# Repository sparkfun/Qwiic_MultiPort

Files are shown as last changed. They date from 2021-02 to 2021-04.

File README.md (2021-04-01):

Qwiic MultiPort
========================================

SparkFun Qwiic MultiPort (https://www.sparkfun.com/products/18012)

[*SparkFun Qwiic MultiPort (BOB-18012)*](https://www.sparkfun.com/products/18012)

Qwiic is a very efficient way to quickly prototype an idea but not all Qwiic-enabled devices have two ports. The SparkFun Qwiic MultiPort adds additional ports to boards that have only one Qwiic port on the I2C bus. Once added, you can use it as a hub to add as many I2C devices to the bus as you need! Included are mounting holes so that the board can be secured to any system.

Repository Contents
-------------------

* **/Hardware** - Eagle design files (.brd, .sch)
* **/Production** - Production panel files (.brd)

Documentation
--------------
* **[Hookup Guide](https://learn.sparkfun.com/tutorials/1659)**

Product Versions
----------------
* [BOB-18012](https://www.sparkfun.com/products/18012) - Initial Release

License Information
-------------------

This product is _**open source**_! 

Please review the LICENSE.md file for license information. 

If you have any questions or concerns on licensing, please contact technical support on our [SparkFun forums](https://forum.sparkfun.com/viewforum.php?f=152).

Distributed as-is; no warranty is given.

- Your friends at SparkFun.

_<COLLABORATION CREDIT>_

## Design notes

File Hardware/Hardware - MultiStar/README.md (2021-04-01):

Qwiic MultiStar
========================================

SparkFun Qwiic MultiStar (https://www.sparkfun.com/news/3803)

[*SparkFun Qwiic MultiStar (BOB-?????)*](https://www.sparkfun.com/news/3803)

The MultiStar was designed for April Fools' Day! This board functions like the MultiPort but with an additional Qwiic connector. The board is also shaped like a Ninja star! The following folders include the Eagle files for the MultiStar. For more information, check out the blog post under "[A Sneak Preview of Our Latest Qwiic Product](https://www.sparkfun.com/news/3803)."

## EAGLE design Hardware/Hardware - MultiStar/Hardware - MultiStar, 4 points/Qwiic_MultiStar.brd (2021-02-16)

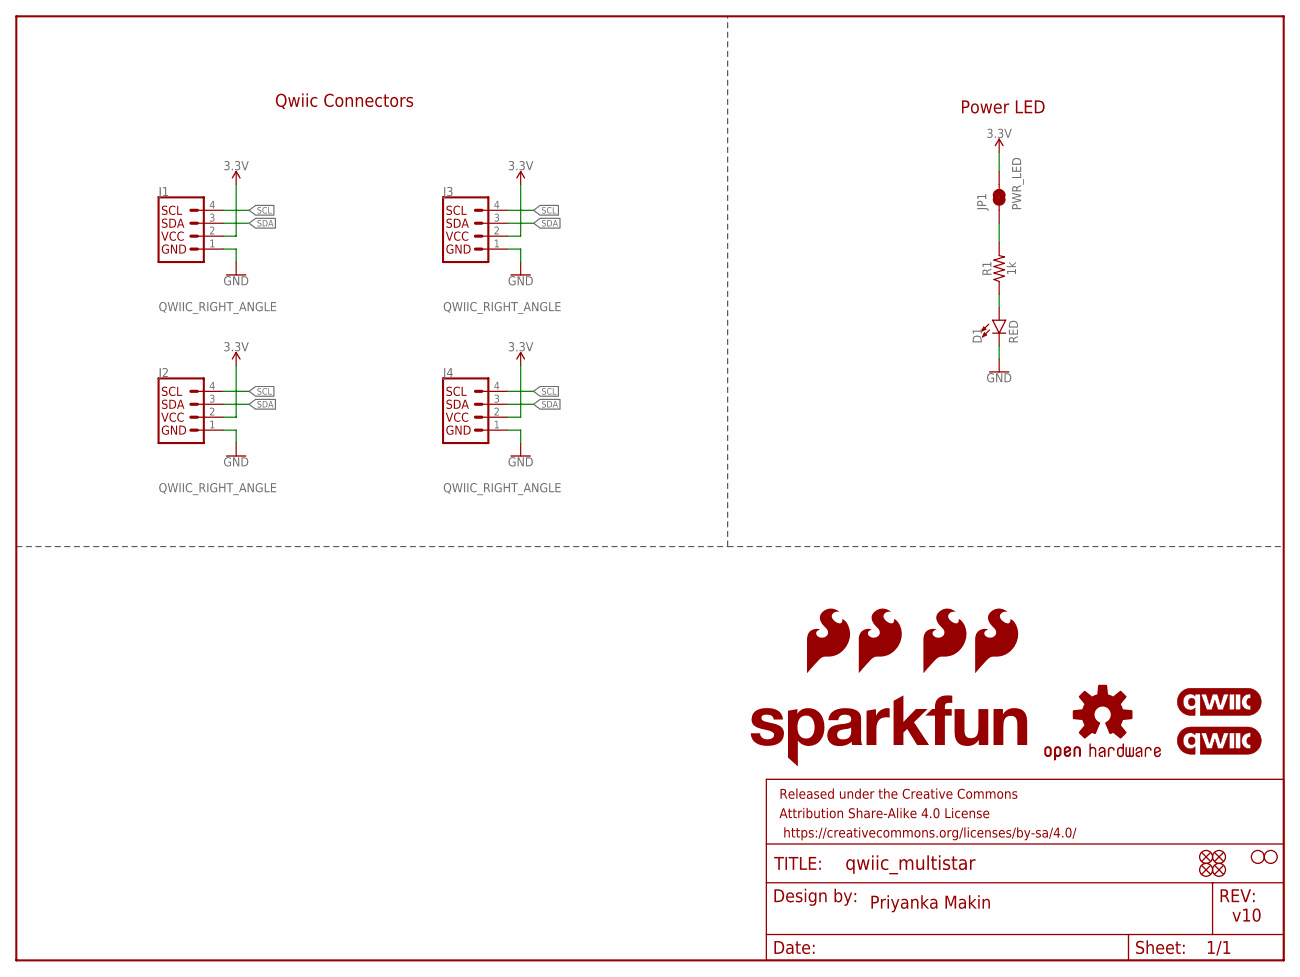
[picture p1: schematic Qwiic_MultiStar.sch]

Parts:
D1: RED; LED-0603
FD1, FD2, FD3, FD4: FIDUCIAL1X2; FIDUCIAL-1X2
FRAME1: FRAME-LETTER; CREATIVE_COMMONS
H1, H2: STAND-OFFTIGHT; STAND-OFF-TIGHT
J1, J2, J3, J4: QWIIC_RIGHT_ANGLE; JST04_1MM_RA
JP1: PWR_LED; SMT-JUMPER_2_NC_TRACE_SILK
LOGO1, LOGO2: QWIIC_LOGO_5MM; QWIIC_5MM
LOGO3: OSHW-LOGOS; OSHW-LOGO-S
LOGO4: SFE_LOGO_NAME.2_INCH; SFE_LOGO_NAME_.2
LOGO5, LOGO6, LOGO7, LOGO8: SFE_LOGO_FLAME.1_INCH; SFE_LOGO_FLAME_.1
R1: 1k; 0603

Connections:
3.3V: J1.2, J2.2, J3.2, J4.2, JP1.2
GND: D1.C, J1.1, J2.1, J3.1, J4.1
unnamed: D1.A, R1.1
unnamed: JP1.1, R1.2
SCL: J1.4, J2.4, J3.4, J4.4
SDA: J1.3, J2.3, J3.3, J4.3

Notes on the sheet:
Priyanka Makin
v10
Qwiic Connectors
Power LED

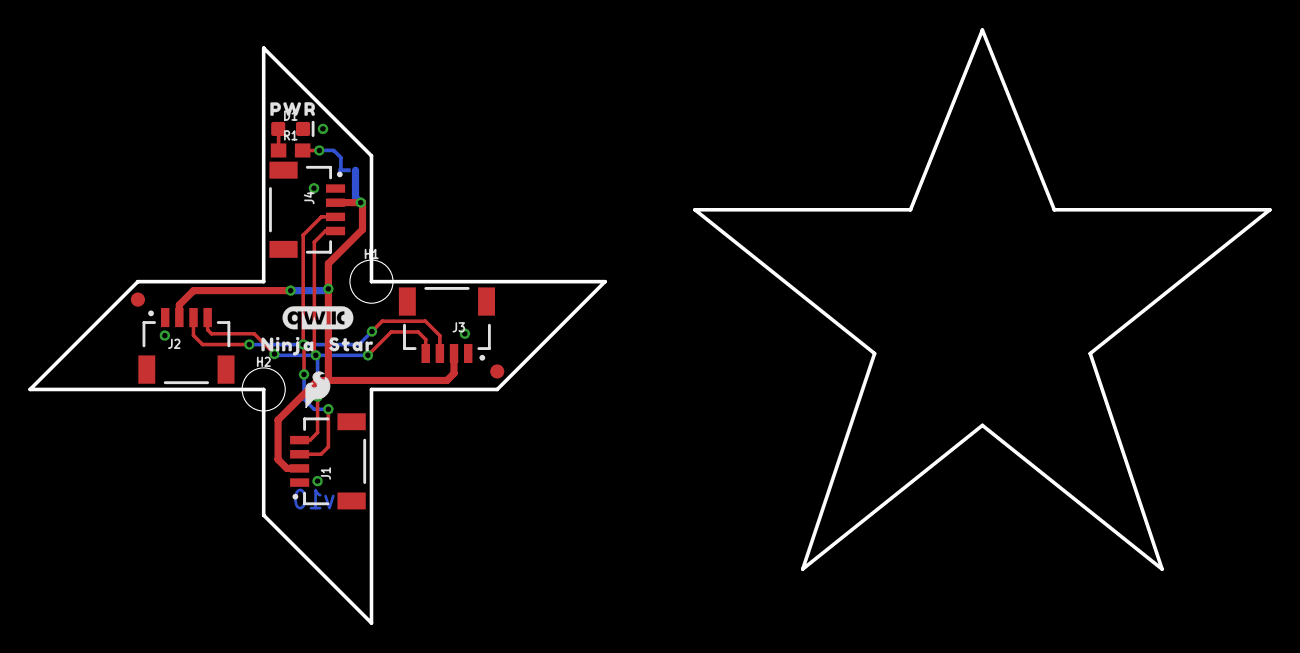
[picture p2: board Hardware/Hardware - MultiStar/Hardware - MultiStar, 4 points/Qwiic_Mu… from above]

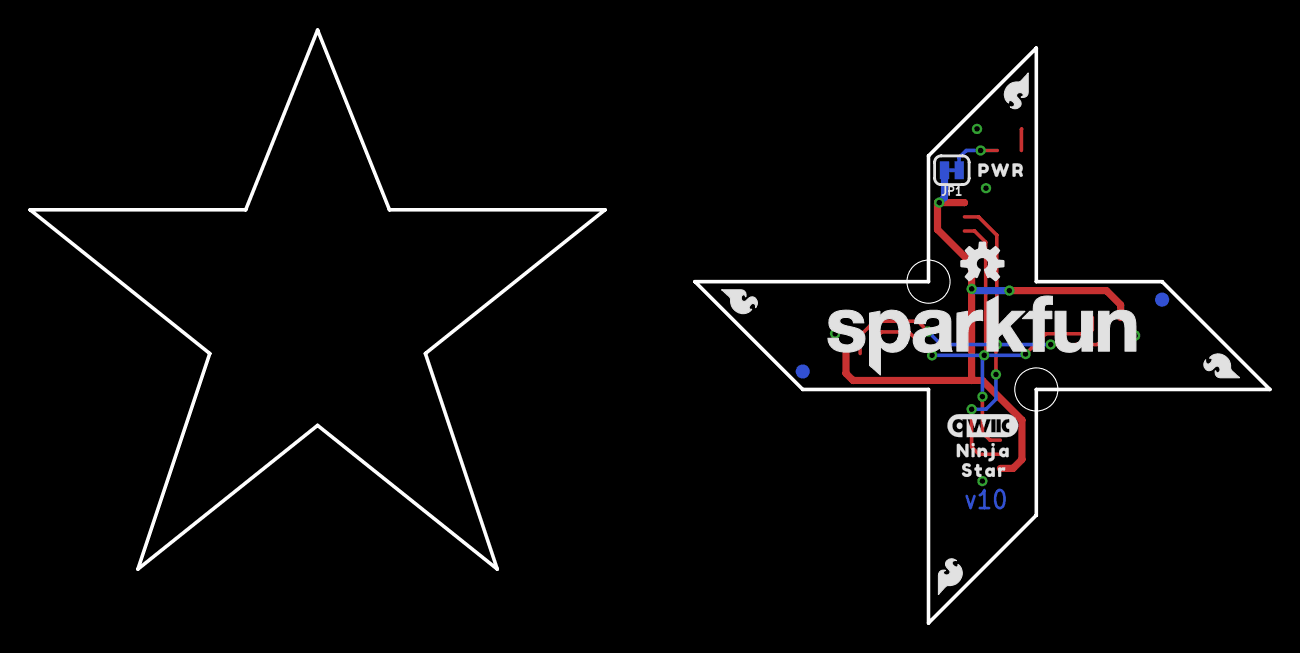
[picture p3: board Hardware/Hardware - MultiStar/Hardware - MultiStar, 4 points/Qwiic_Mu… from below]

Board: 2 copper layers, 40.6 x 40.6 mm, 29 parts (13 on the bottom side), 6 nets.

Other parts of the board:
U$2: SFE_LOGO_FLAME_.1
U$3, U$5: NINJA0
U$4, U$9: PWR0
U$6, U$7: STAR0

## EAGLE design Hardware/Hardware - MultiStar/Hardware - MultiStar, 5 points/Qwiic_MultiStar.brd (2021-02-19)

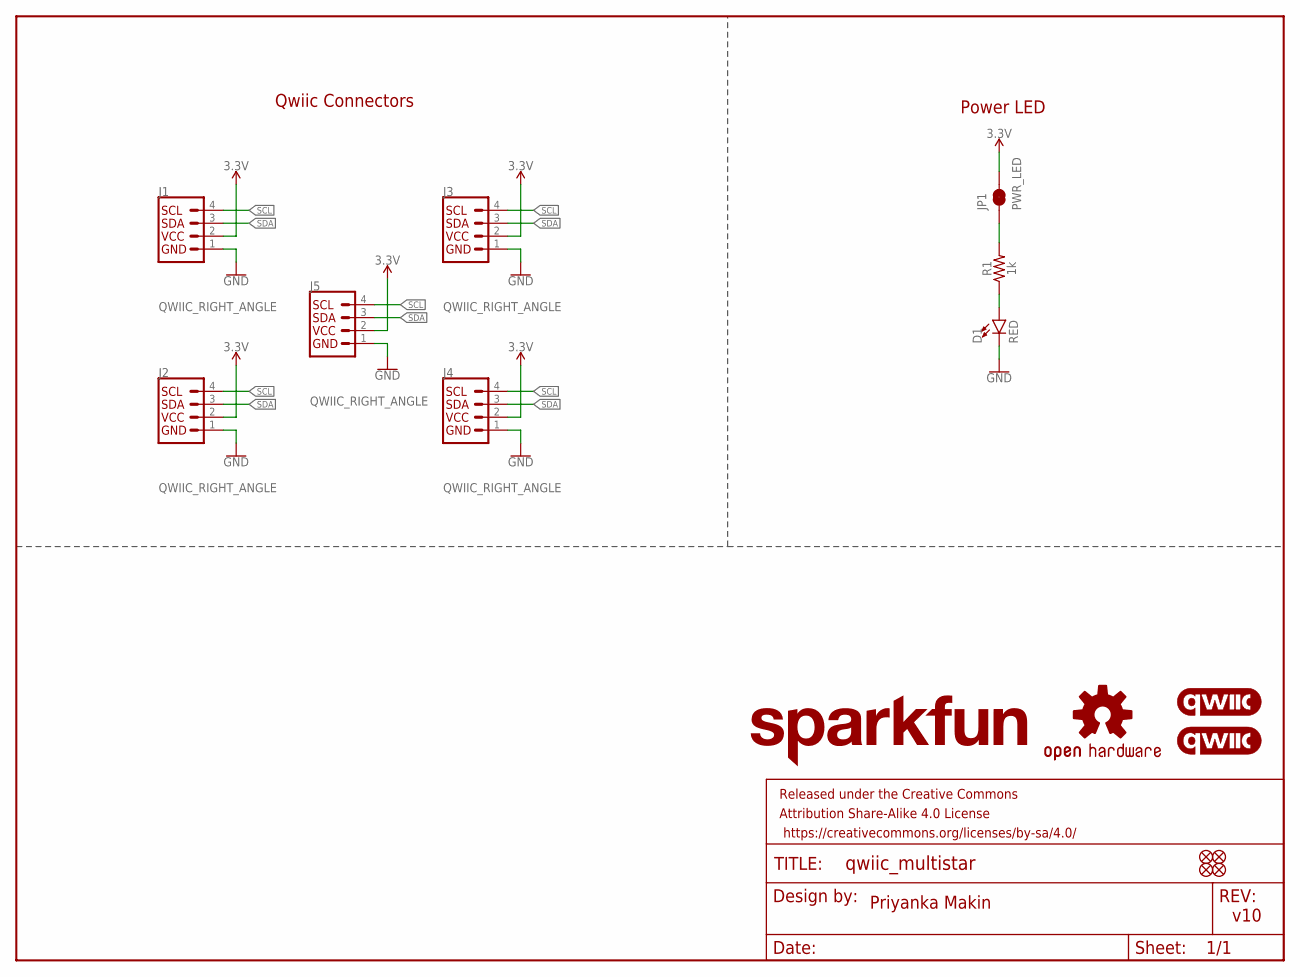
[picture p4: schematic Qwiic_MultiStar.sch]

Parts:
D1: RED; LED-0603
FD1, FD2, FD3, FD4: FIDUCIAL1X2; FIDUCIAL-1X2
FRAME1: FRAME-LETTER; CREATIVE_COMMONS
J1, J2, J3, J4, J5: QWIIC_RIGHT_ANGLE; JST04_1MM_RA
JP1: PWR_LED; SMT-JUMPER_2_NC_TRACE_SILK
LOGO1, LOGO2: QWIIC_LOGO_5MM; QWIIC_5MM
LOGO3: OSHW-LOGOS; OSHW-LOGO-S
LOGO4: SFE_LOGO_NAME.2_INCH; SFE_LOGO_NAME_.2
R1: 1k; 0603

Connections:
3.3V: J1.2, J2.2, J3.2, J4.2, J5.2, JP1.2
GND: D1.C, J1.1, J2.1, J3.1, J4.1, J5.1
unnamed: D1.A, R1.1
unnamed: JP1.1, R1.2
SCL: J1.4, J2.4, J3.4, J4.4, J5.4
SDA: J1.3, J2.3, J3.3, J4.3, J5.3

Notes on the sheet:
Priyanka Makin
v10
Qwiic Connectors
Power LED

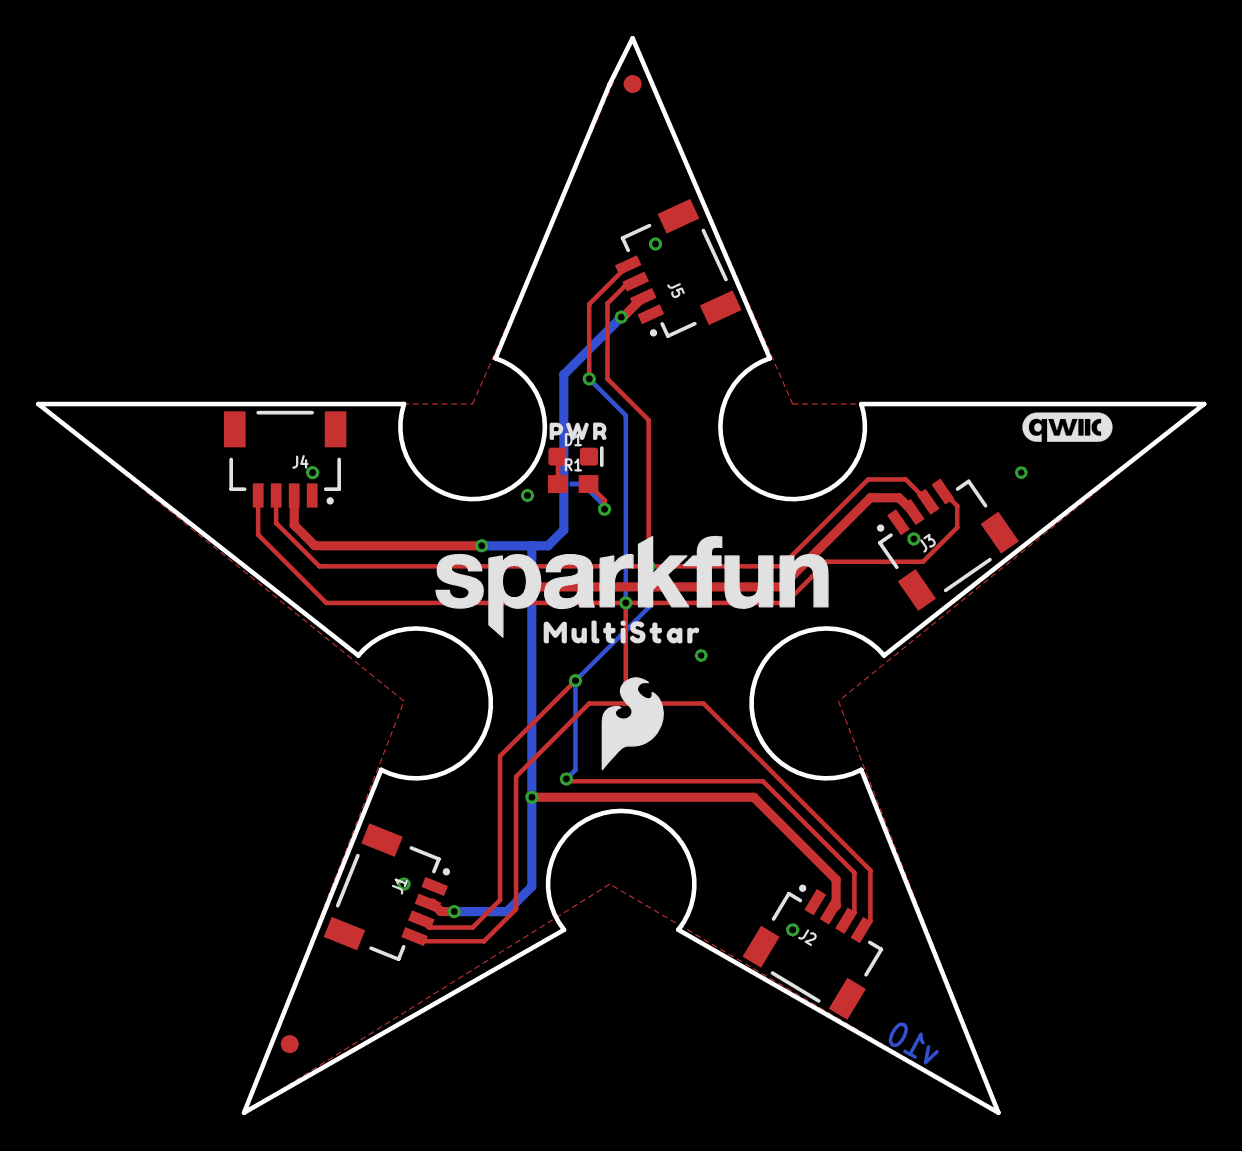
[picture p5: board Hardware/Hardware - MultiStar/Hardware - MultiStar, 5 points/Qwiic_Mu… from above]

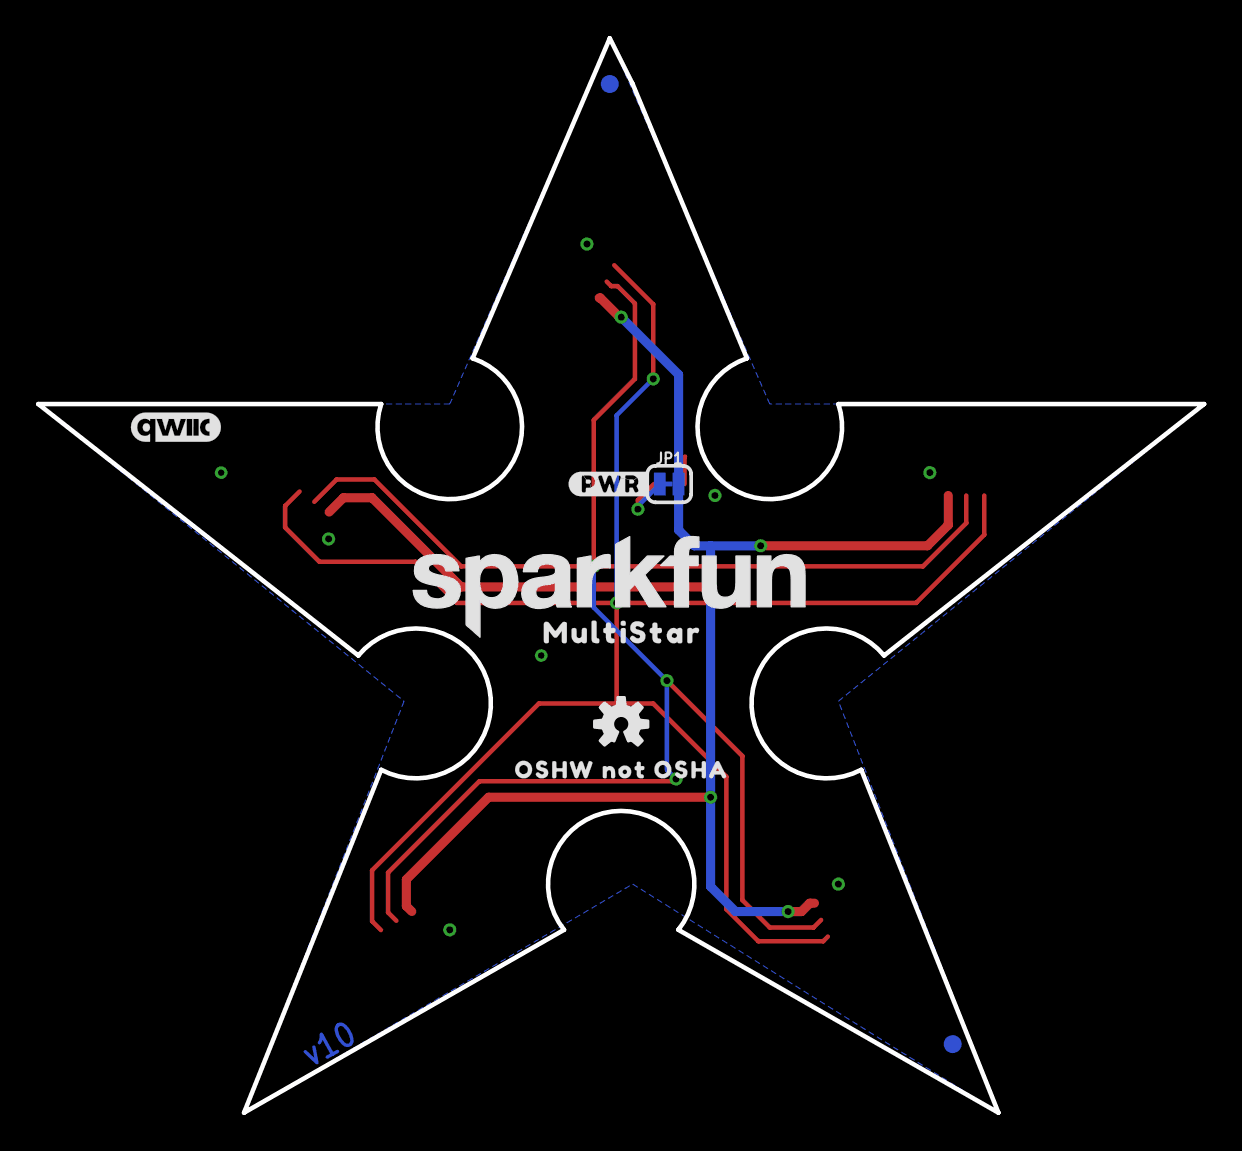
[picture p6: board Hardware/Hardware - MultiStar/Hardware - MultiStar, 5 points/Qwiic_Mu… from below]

Board: 2 copper layers, 64.8 x 59.7 mm, 24 parts (9 on the bottom side), 6 nets.

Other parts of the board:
LOGO5: SFE_LOGO_NAME.2_INCH; SFE_LOGO_NAME_.2
U$1: OSHW_NOT_OSHA0
U$2: SFE_LOGO_FLAME_.2
U$3, U$5: MULTISTAR0
U$6: #PWR#0
U$9: PWR0

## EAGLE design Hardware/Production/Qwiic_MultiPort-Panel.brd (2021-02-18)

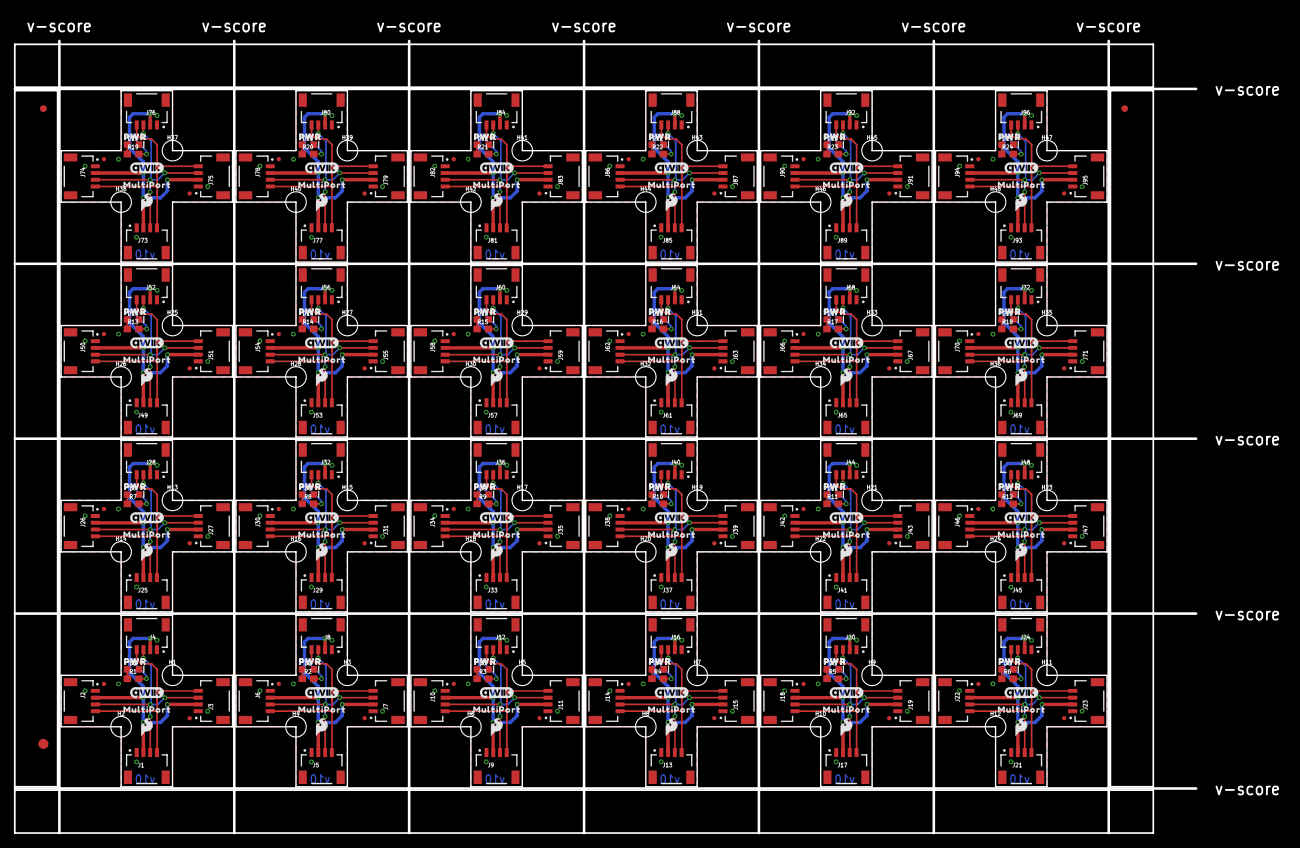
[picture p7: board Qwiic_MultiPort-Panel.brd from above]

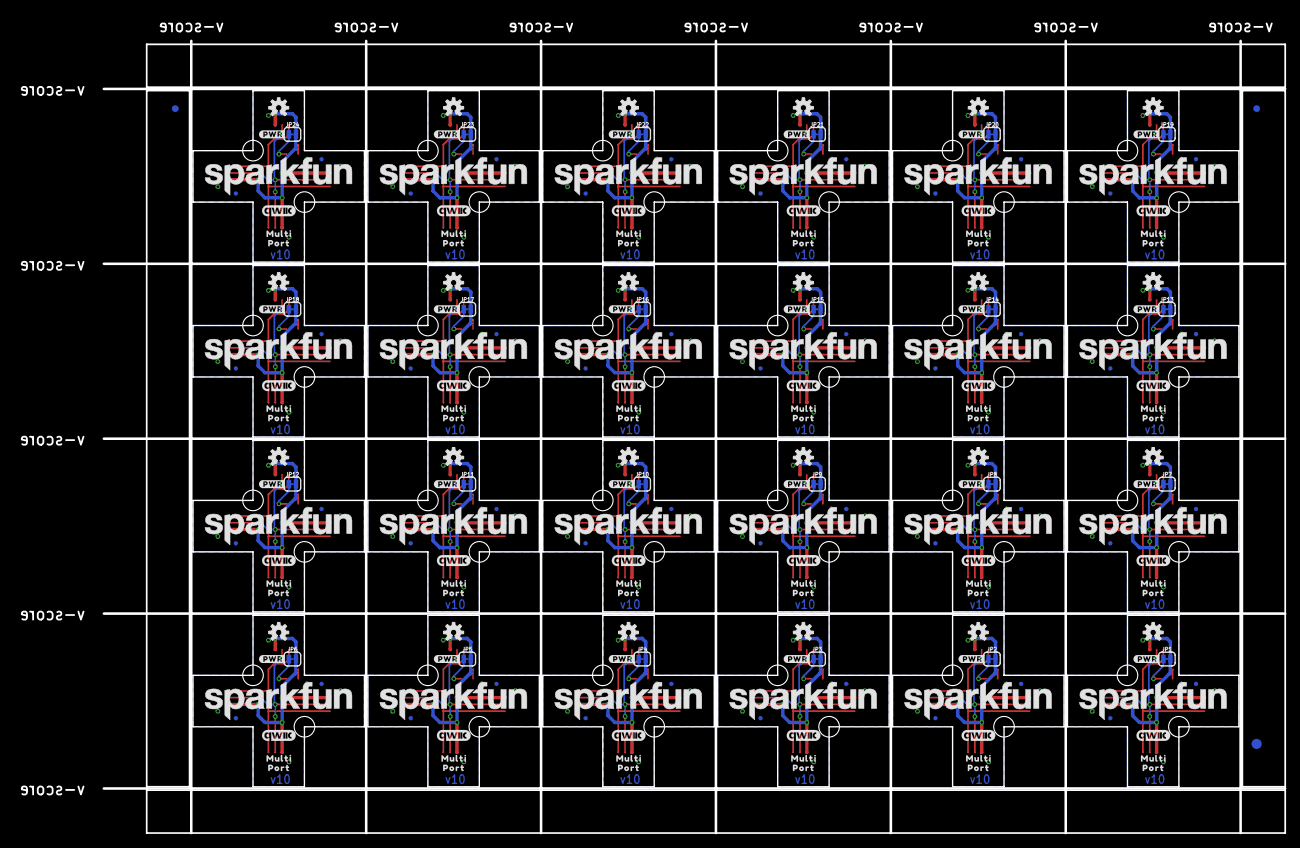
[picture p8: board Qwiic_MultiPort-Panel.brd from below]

Board: 2 copper layers, 175.0 x 117.3 mm, 582 parts (219 on the bottom side), 144 nets.

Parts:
D1, D2, D3, D4, D5, D6, D7, D8, D9, D10, D11, D12, D13, D14, D15, D16, D17, D18, D19, D20, D21, D22, D23, D24: RED; LED-0603
E$1, E$2, E$3, E$4: FIDUCIAL-1X2
E$5, E$6: FIDUCIAL-1.5X3
FD1, FD2, FD3, FD4, FD5, FD6, FD7, FD8, FD9, FD10, FD11, FD12, FD13, FD14, FD15, FD16, FD17, FD18, FD19, FD20, FD21, FD22, FD23, FD24, FD25, FD26, FD27, FD28, FD29, FD30, FD31, FD32, FD33, FD34, FD35, FD36, FD37, FD38, FD39, FD40, FD41, FD42, FD43, FD44, FD45, FD46, FD47, FD48, FD49, FD50, FD51, FD52, FD53, FD54, FD55, FD56, FD57, FD58, FD59, FD60, FD61, FD62, FD63, FD64, FD65, FD66, FD67, FD68, FD69, FD70, FD71, FD72, FD73, FD74, FD75, FD76, FD77, FD78, FD79, FD80, FD81, FD82, FD83, FD84, FD85, FD86, FD87, FD88, FD89, FD90, FD91, FD92, FD93, FD94, FD95, FD96: FIDUCIALUFIDUCIAL; FIDUCIAL-MICRO
H1, H2, H3, H4, H5, H6, H7, H8, H9, H10, H11, H12, H13, H14, H15, H16, H17, H18, H19, H20, H21, H22, H23, H24, H25, H26, H27, H28, H29, H30, H31, H32, H33, H34, H35, H36, H37, H38, H39, H40, H41, H42, H43, H44, H45, H46, H47, H48: STAND-OFFTIGHT; STAND-OFF-TIGHT
J1, J2, J3, J4, J5, J6, J7, J8, J9, J10, J11, J12, J13, J14, J15, J16, J17, J18, J19, J20, J21, J22, J23, J24, J25, J26, J27, J28, J29, J30, J31, J32, J33, J34, J35, J36, J37, J38, J39, J40, J41, J42, J43, J44, J45, J46, J47, J48, J49, J50, J51, J52, J53, J54, J55, J56, J57, J58, J59, J60, J61, J62, J63, J64, J65, J66, J67, J68, J69, J70, J71, J72, J73, J74, J75, J76, J77, J78, J79, J80, J81, J82, J83, J84, J85, J86, J87, J88, J89, J90, J91, J92, J93, J94, J95, J96: QWIIC_RIGHT_ANGLE; JST04_1MM_RA
JP1, JP2, JP3, JP4, JP5, JP6, JP7, JP8, JP9, JP10, JP11, JP12, JP13, JP14, JP15, JP16, JP17, JP18, JP19, JP20, JP21, JP22, JP23, JP24: PWR_LED; SMT-JUMPER_2_NC_TRACE_SILK
LOGO1, LOGO2, LOGO5, LOGO6, LOGO9, LOGO10, LOGO13, LOGO14, LOGO17, LOGO18, LOGO21, LOGO22, LOGO25, LOGO26, LOGO29, LOGO30, LOGO33, LOGO34, LOGO37, LOGO38, LOGO41, LOGO42, LOGO45, LOGO46, LOGO49, LOGO50, LOGO53, LOGO54, LOGO57, LOGO58, LOGO61, LOGO62, LOGO65, LOGO66, LOGO69, LOGO70, LOGO73, LOGO74, LOGO77, LOGO78, LOGO81, LOGO82, LOGO85, LOGO86, LOGO89, LOGO90, LOGO93, LOGO94: QWIIC_LOGO_5MM; QWIIC_5MM
LOGO3, LOGO7, LOGO11, LOGO15, LOGO19, LOGO23, LOGO27, LOGO31, LOGO35, LOGO39, LOGO43, LOGO47, LOGO51, LOGO55, LOGO59, LOGO63, LOGO67, LOGO71, LOGO75, LOGO79, LOGO83, LOGO87, LOGO91, LOGO95: OSHW-LOGOS; OSHW-LOGO-S
LOGO4, LOGO8, LOGO12, LOGO16, LOGO20, LOGO24, LOGO28, LOGO32, LOGO36, LOGO40, LOGO44, LOGO48, LOGO52, LOGO56, LOGO60, LOGO64, LOGO68, LOGO72, LOGO76, LOGO80, LOGO84, LOGO88, LOGO92, LOGO96: SFE_LOGO_NAME.2_INCH; SFE_LOGO_NAME_.2
R1, R2, R3, R4, R5, R6, R7, R8, R9, R10, R11, R12, R13, R14, R15, R16, R17, R18, R19, R20, R21, R22, R23, R24: 1k; 0603
U$1, U$6, U$9, U$10, U$16, U$19, U$23, U$26, U$30, U$33, U$37, U$40, U$44, U$47, U$51, U$54, U$58, U$61, U$65, U$68, U$72, U$75, U$79, U$82, U$86, U$89, U$93, U$96, U$100, U$103, U$107, U$110, U$114, U$117, U$121, U$124, U$128, U$131, U$135, U$138, U$142, U$145, U$149, U$152, U$156, U$159, U$163, U$166: PWR0
U$2, U$3, U$15, U$22, U$29, U$36, U$43, U$50, U$57, U$64, U$71, U$78, U$85, U$92, U$99, U$106, U$113, U$120, U$127, U$134, U$141, U$148, U$155, U$162: SFE_LOGO_FLAME_.1
U$4, U$12, U$20, U$27, U$34, U$41, U$48, U$55, U$62, U$69, U$76, U$83, U$90, U$97, U$104, U$111, U$118, U$125, U$132, U$139, U$146, U$153, U$160, U$167: MULTIPORT0
U$5, U$14, U$21, U$28, U$35, U$42, U$49, U$56, U$63, U$70, U$77, U$84, U$91, U$98, U$105, U$112, U$119, U$126, U$133, U$140, U$147, U$154, U$161, U$168: #PWR#0
U$7, U$11, U$17, U$24, U$31, U$38, U$45, U$52, U$59, U$66, U$73, U$80, U$87, U$94, U$101, U$108, U$115, U$122, U$129, U$136, U$143, U$150, U$157, U$164: MULTI0
U$8, U$13, U$18, U$25, U$32, U$39, U$46, U$53, U$60, U$67, U$74, U$81, U$88, U$95, U$102, U$109, U$116, U$123, U$130, U$137, U$144, U$151, U$158, U$165: PORT0

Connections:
3.3V: J1.2, J2.2, J3.2, J4.2, JP1.2
3.3V1: J5.2, J6.2, J7.2, J8.2, JP2.2
3.3V2: J9.2, J10.2, J11.2, J12.2, JP3.2
3.3V3: J13.2, J14.2, J15.2, J16.2, JP4.2
3.3V4: J17.2, J18.2, J19.2, J20.2, JP5.2
3.3V5: J21.2, J22.2, J23.2, J24.2, JP6.2
3.3V6: J25.2, J26.2, J27.2, J28.2, JP7.2
3.3V7: J29.2, J30.2, J31.2, J32.2, JP8.2
3.3V8: J33.2, J34.2, J35.2, J36.2, JP9.2
3.3V9: J37.2, J38.2, J39.2, J40.2, JP10.2
3.3V10: J41.2, J42.2, J43.2, J44.2, JP11.2
3.3V11: J45.2, J46.2, J47.2, J48.2, JP12.2
3.3V12: J49.2, J50.2, J51.2, J52.2, JP13.2
3.3V13: J53.2, J54.2, J55.2, J56.2, JP14.2
3.3V14: J57.2, J58.2, J59.2, J60.2, JP15.2
3.3V15: J61.2, J62.2, J63.2, J64.2, JP16.2
3.3V16: J65.2, J66.2, J67.2, J68.2, JP17.2
3.3V17: J69.2, J70.2, J71.2, J72.2, JP18.2
3.3V18: J73.2, J74.2, J75.2, J76.2, JP19.2
3.3V19: J77.2, J78.2, J79.2, J80.2, JP20.2
3.3V20: J81.2, J82.2, J83.2, J84.2, JP21.2
3.3V21: J85.2, J86.2, J87.2, J88.2, JP22.2
3.3V22: J89.2, J90.2, J91.2, J92.2, JP23.2
3.3V23: J93.2, J94.2, J95.2, J96.2, JP24.2
GND: D1.C, J1.1, J2.1, J3.1, J4.1
GND1: D2.C, J5.1, J6.1, J7.1, J8.1
GND2: D3.C, J9.1, J10.1, J11.1, J12.1
GND3: D4.C, J13.1, J14.1, J15.1, J16.1
GND4: D5.C, J17.1, J18.1, J19.1, J20.1
GND5: D6.C, J21.1, J22.1, J23.1, J24.1
GND6: D7.C, J25.1, J26.1, J27.1, J28.1
GND7: D8.C, J29.1, J30.1, J31.1, J32.1
GND8: D9.C, J33.1, J34.1, J35.1, J36.1
GND9: D10.C, J37.1, J38.1, J39.1, J40.1
GND10: D11.C, J41.1, J42.1, J43.1, J44.1
GND11: D12.C, J45.1, J46.1, J47.1, J48.1
GND12: D13.C, J49.1, J50.1, J51.1, J52.1
GND13: D14.C, J53.1, J54.1, J55.1, J56.1
GND14: D15.C, J57.1, J58.1, J59.1, J60.1
GND15: D16.C, J61.1, J62.1, J63.1, J64.1
GND16: D17.C, J65.1, J66.1, J67.1, J68.1
GND17: D18.C, J69.1, J70.1, J71.1, J72.1
GND18: D19.C, J73.1, J74.1, J75.1, J76.1
GND19: D20.C, J77.1, J78.1, J79.1, J80.1
GND20: D21.C, J81.1, J82.1, J83.1, J84.1
GND21: D22.C, J85.1, J86.1, J87.1, J88.1
GND22: D23.C, J89.1, J90.1, J91.1, J92.1
GND23: D24.C, J93.1, J94.1, J95.1, J96.1
unnamed: D1.A, R1.1
unnamed: JP1.1, R1.2
unnamed: D2.A, R2.1
unnamed: JP2.1, R2.2
unnamed: D3.A, R3.1
unnamed: JP3.1, R3.2
unnamed: D4.A, R4.1
unnamed: JP4.1, R4.2
unnamed: D5.A, R5.1
unnamed: JP5.1, R5.2
unnamed: D6.A, R6.1
unnamed: JP6.1, R6.2
unnamed: D7.A, R7.1
unnamed: JP7.1, R7.2
unnamed: D8.A, R8.1
unnamed: JP8.1, R8.2
unnamed: D9.A, R9.1
unnamed: JP9.1, R9.2
unnamed: D10.A, R10.1
unnamed: JP10.1, R10.2
unnamed: D11.A, R11.1
unnamed: JP11.1, R11.2
unnamed: D12.A, R12.1
unnamed: JP12.1, R12.2
unnamed: D13.A, R13.1
unnamed: JP13.1, R13.2
unnamed: D14.A, R14.1
unnamed: JP14.1, R14.2
unnamed: D15.A, R15.1
unnamed: JP15.1, R15.2
unnamed: D16.A, R16.1
unnamed: JP16.1, R16.2
unnamed: D17.A, R17.1
unnamed: JP17.1, R17.2
unnamed: D18.A, R18.1
unnamed: JP18.1, R18.2
unnamed: D19.A, R19.1
unnamed: JP19.1, R19.2
unnamed: D20.A, R20.1
unnamed: JP20.1, R20.2
unnamed: D21.A, R21.1
unnamed: JP21.1, R21.2
unnamed: D22.A, R22.1
unnamed: JP22.1, R22.2
unnamed: D23.A, R23.1
unnamed: JP23.1, R23.2
unnamed: D24.A, R24.1
unnamed: JP24.1, R24.2
SCL: J1.4, J2.4, J3.4, J4.4
SCL1: J5.4, J6.4, J7.4, J8.4
SCL2: J9.4, J10.4, J11.4, J12.4
SCL3: J13.4, J14.4, J15.4, J16.4
SCL4: J17.4, J18.4, J19.4, J20.4
SCL5: J21.4, J22.4, J23.4, J24.4
SCL6: J25.4, J26.4, J27.4, J28.4
SCL7: J29.4, J30.4, J31.4, J32.4
SCL8: J33.4, J34.4, J35.4, J36.4
SCL9: J37.4, J38.4, J39.4, J40.4
SCL10: J41.4, J42.4, J43.4, J44.4
SCL11: J45.4, J46.4, J47.4, J48.4
SCL12: J49.4, J50.4, J51.4, J52.4
SCL13: J53.4, J54.4, J55.4, J56.4
SCL14: J57.4, J58.4, J59.4, J60.4
SCL15: J61.4, J62.4, J63.4, J64.4
SCL16: J65.4, J66.4, J67.4, J68.4
SCL17: J69.4, J70.4, J71.4, J72.4
SCL18: J73.4, J74.4, J75.4, J76.4
SCL19: J77.4, J78.4, J79.4, J80.4
SCL20: J81.4, J82.4, J83.4, J84.4
SCL21: J85.4, J86.4, J87.4, J88.4
SCL22: J89.4, J90.4, J91.4, J92.4
SCL23: J93.4, J94.4, J95.4, J96.4
SDA: J1.3, J2.3, J3.3, J4.3
SDA1: J5.3, J6.3, J7.3, J8.3
SDA2: J9.3, J10.3, J11.3, J12.3
SDA3: J13.3, J14.3, J15.3, J16.3
SDA4: J17.3, J18.3, J19.3, J20.3
SDA5: J21.3, J22.3, J23.3, J24.3
SDA6: J25.3, J26.3, J27.3, J28.3
SDA7: J29.3, J30.3, J31.3, J32.3
SDA8: J33.3, J34.3, J35.3, J36.3
SDA9: J37.3, J38.3, J39.3, J40.3
SDA10: J41.3, J42.3, J43.3, J44.3
SDA11: J45.3, J46.3, J47.3, J48.3
SDA12: J49.3, J50.3, J51.3, J52.3
SDA13: J53.3, J54.3, J55.3, J56.3
SDA14: J57.3, J58.3, J59.3, J60.3
SDA15: J61.3, J62.3, J63.3, J64.3
SDA16: J65.3, J66.3, J67.3, J68.3
SDA17: J69.3, J70.3, J71.3, J72.3
SDA18: J73.3, J74.3, J75.3, J76.3
SDA19: J77.3, J78.3, J79.3, J80.3
SDA20: J81.3, J82.3, J83.3, J84.3
SDA21: J85.3, J86.3, J87.3, J88.3
SDA22: J89.3, J90.3, J91.3, J92.3
SDA23: J93.3, J94.3, J95.3, J96.3

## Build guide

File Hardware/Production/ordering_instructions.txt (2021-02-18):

panel size, 169x117mm
PCB thickness, 1.6mm
number of layers, 2
soldermask color, Red
silkscreen color, White
oz copper, 1oz
finish, HASL lead free
stencils, top
pcs per panel, 24
min trace width, 0.2540mm / 0.0100in
min drill size, 0.3810mm / 0.0150in

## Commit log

2021-02-08 Add power LED to board
    [Qwiic_Multi_Port_Board.brd, Qwiic_Multi_Port_Board.sch]
2021-02-08 Update SFE logos on board
    [Qwiic_Multi_Port_Board.brd]
2021-02-08 Update silk screen
    [Qwiic_Multi_Port_Board.brd]
2021-02-08 Update silkscreen
    [Qwiic_Multi_Port_Board.brd]
2021-02-09 Created Qwiic Ninja Star
    [Qwiic_Ninja_Star.brd, Qwiic_Ninja_Star.sch]
2021-02-10 Multi Port: Design Review Changes
    Added jumper on PWR LED
    Added fiducials
    Added OSHW, qwiic, SF logo as device on the schematic
    Moved traces on top layer to avoid screws
    Decided against:
    un-populated I2C pullups -- not enough space
    [Qwiic_Multi_Port_Board.brd, Qwiic_Multi_Port_Board.sch]
2021-02-10 Ninja Star: Design Review Changes
    Added jumper to PWR LED
    Added OSHW, qwiic, SF, and flame logo devices to schematic
    Tried my best to move traces out from underneath screws
    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
    [Qwiic_Ninja_Star.brd, Qwiic_Ninja_Star.sch]
2021-02-10 Update silkscreen name to "Ninja Star"
    [Qwiic_Ninja_Star.brd]
2021-02-10 Completed Engineering checklist
    [Qwiic_Multi_Port_Board.brd, Qwiic_Multi_Port_Board.sch, Qwiic_Ninja_Star.brd]
2021-02-15 Created star-shaped Qwiic Ninja Star and updated Multi Port
    Updated Qwiic Multi Port with QC Double check concerns:
    Removed wire stub
    Approve DRC errors
    Move via to not clip the t in "Port" on top
    Moved power jumper and silk so that jumper silk and SF logo don't overlap
    [Qwiic_Multi_Port_Board.brd, Qwiic_Ninja_Star.brd, Qwiic_Ninja_Star.sch]
2021-02-16 Wired qwiic ninja star
    [Qwiic_Ninja_Star.brd, Qwiic_Ninja_Star.sch]
2021-02-16 Renamed the boards to CamelCase
    Multi Port --> MultiPort
    Ninja Star --> MultiStar
    [Qwiic_MultiPort.brd, Qwiic_MultiPort.sch, Qwiic_MultiStar.brd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]
2021-02-17 MultiPort - Pete's notes
    Reduced fiducial size to Micro
    Moved PWR LED jumper and generated inverted label for jumper
    [Qwiic_MultiPort.brd, Qwiic_MultiPort.sch]
2021-02-17 MultiPort - re-panelized
    [Qwiic_MultiPort-Panel.GBL, Qwiic_MultiPort-Panel.GBO, Qwiic_MultiPort-Panel.GBP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]
2021-02-18 re-route MultiPort in daisy chain configuration
    [Qwiic_MultiPort.brd, Qwiic_MultiStar.brd]
2021-02-18 Re-panelized Qwiic MultiPort
    Less than 7x5 inches
    [Qwiic_MultiPort-Panel.GBL, Qwiic_MultiPort-Panel.GBO, Qwiic_MultiPort-Panel.GBS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]
2021-02-19 Generate gerbers for Qwiic MultiStar
    [Qwiic_MultiStar.GBL, Qwiic_MultiStar.GBO, Qwiic_MultiStar.GBP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]
2021-04-01 Moving MultiStar into Subfolder
    [Qwiic_MultiStar.GBL, Qwiic_MultiStar.GBO, Qwiic_MultiStar.GBP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]

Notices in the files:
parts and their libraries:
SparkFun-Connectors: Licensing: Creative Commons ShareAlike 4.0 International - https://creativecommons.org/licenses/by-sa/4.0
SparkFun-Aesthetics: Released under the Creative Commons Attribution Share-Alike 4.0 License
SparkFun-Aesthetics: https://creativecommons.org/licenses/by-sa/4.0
